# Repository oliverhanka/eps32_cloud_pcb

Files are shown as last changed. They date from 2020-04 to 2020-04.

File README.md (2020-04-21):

# ESP32 low power sensor node

This is a simplistic ESP32 based sensor node with a focus on very low power consumption while beeing idle. This means, external components are keept to a minimum and the selected LDO has a very low power consumption. The board can be supplied with 3.3V directly or by using the on-board LDO (max. 6V input) to generate the required 3.3V. *NOTE: The LDO_EN solder jumper must be closed in order to use the LDO.*

#### Theoretical power consumption
These values have not been verified by measurements and do not take the passive components into account.

Power consumption while beeing in hibernation:
| Active component | Current | Power |
| --- | --- | --- |
| ESP32 (in hibernation)  | 5𝜇A @ 3.3V  | 16.5𝜇W |
| LDO  | 8𝜇A @ 5V  | 40𝜇W |
| **Total**  | **11.3𝜇A @ 5V**  | **56.5𝜇W** |

While beeing active and transmitting via Wifi (BLE off):
| Active component | Current | Power |
| --- | --- | --- |
| ESP32 (240MHz, Wifi tx)  | 240mA @ 3.3V  | 792mW |
| LDO  | 8𝜇A @ 5V  | 40𝜇W |
| **Total**  | **158.4mA @ 5V**  | **792mW** |

## Connectors / headers / solder jumper

| Connector | Purpose |
| --- | --- |
| J1 | I2C, power via GPIO14 |
| J2 | power connector, JST-PH |
| J3 | power connector, USB-C |
| J4 | programming interface, compatible with [ESP-Prog](https://github.com/espressif/esp-iot-solution/blob/master/documents/evaluation_boards/ESP-Prog_guide_en.md) |
| J5 | various GPIOs or ADC and SPI, VCC, GND |
| J6 | GPIO (e.g., for WS2812, power via GPIO2) |

| Solder jumper | Purpose |
| --- | --- |
| LED_EN | Enable blue LED D1 controlled by GPIO12) |
| LDO_EN | Enable LDO (e.g., for power via USB-C) |

## Build

### Manufactured PCB 
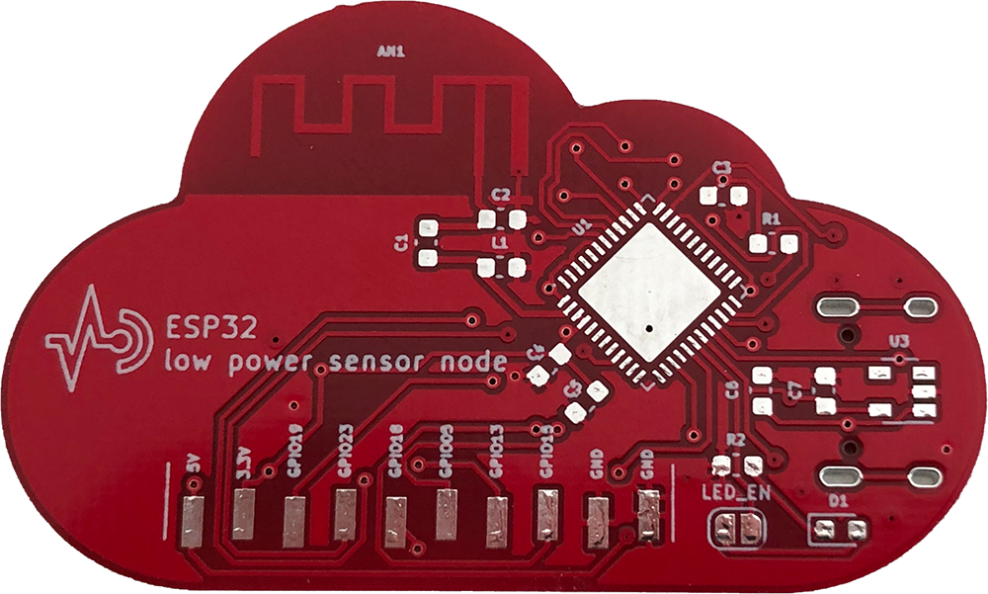
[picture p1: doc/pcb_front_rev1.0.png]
PCB front
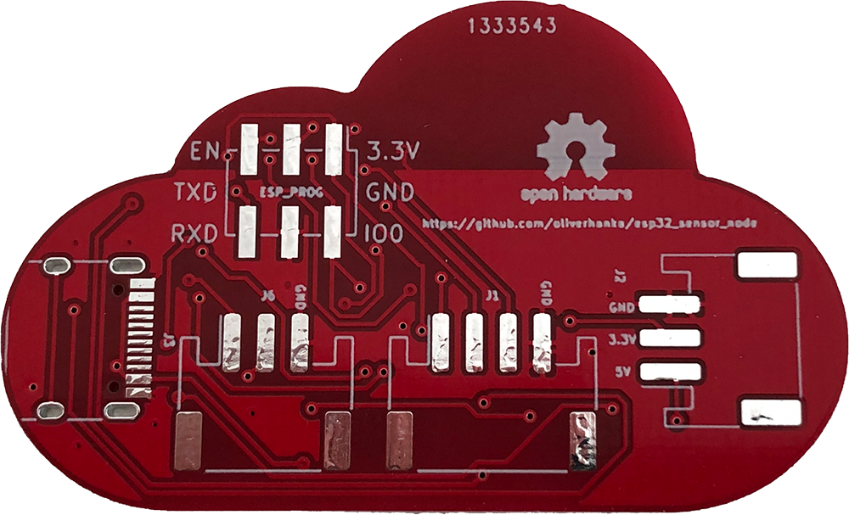
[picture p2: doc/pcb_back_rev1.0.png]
PCB back
 | 
------------ | -------------
frontside rev 1.0 | backside rev 1.0

### Assembled PCB

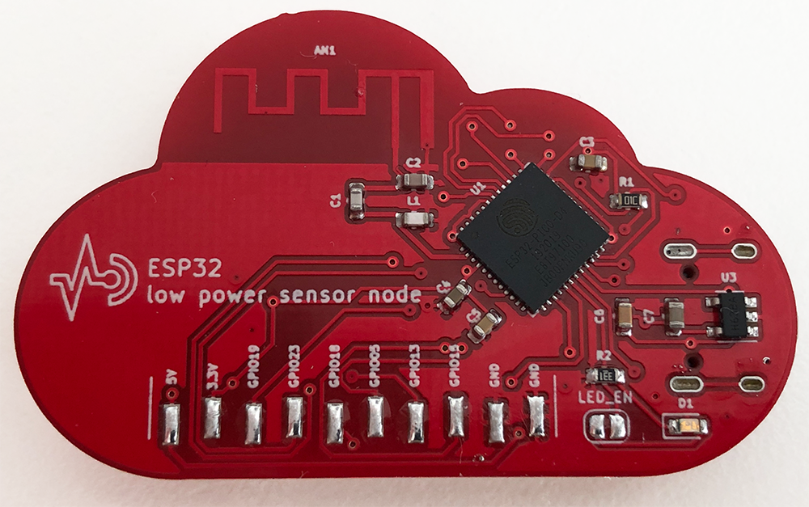
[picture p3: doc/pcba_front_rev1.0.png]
PCBA front
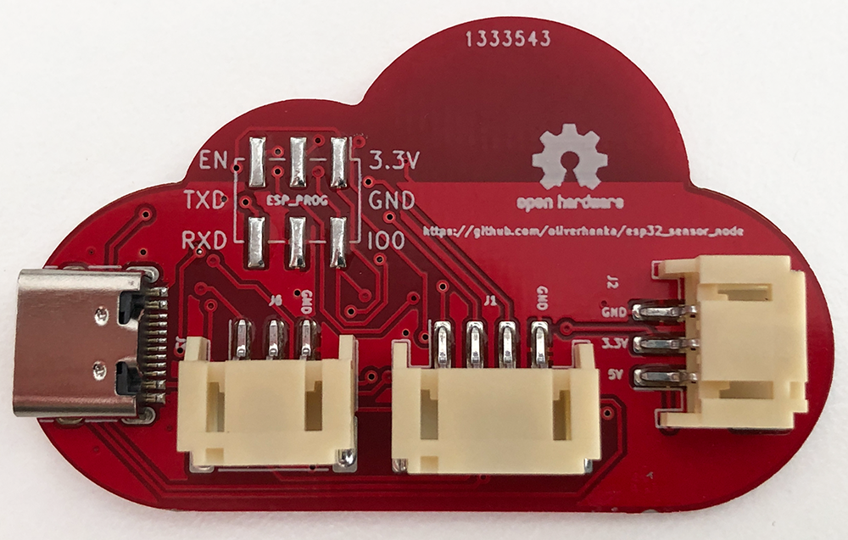
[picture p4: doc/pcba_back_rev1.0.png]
PCBA back
 | 
------------ | -------------
assembled front rev 1.0 | assembled back rev 1.0

### Bill of materials (BOM)

| Designator | Manufacturer Part Number | Qty |
| --- | --- |	--- |
|J6, J2 |	S3B-PH-SM4-TB(LF)(SN) |	2 |
|J1 |	S4B-PH-SM4-TB(LF)(SN) |	1 |
|J3 |	TYPE-C-31-M-12 |	1 |
|R1 |	10kΩ (0603) |	1 |
|R2 |	330Ω (0603) |	1 |
|D1 |	LED (0603) |	1 |
|L1 |	1.6nH (0603) |	1 |
|C7 |	22uF (0603) |	1 |
|C6 |	0.1uf (0603) |	1 |
|C5, C3 |	0.1uF/25V (0603) |	2 |
|C4 |	10uF/6.3V (0603) |	1 |
|C2 |	2.7pF (0603) |	1 |
|C1 |	4.7pF (0603) |	1 |
|U1 |	ESP32-PICO-D4 |	1 |
|U3 |	XC6220B331MR-G |	1 |

---

## Changelog
rev 1.2
- **BREAKING CHANGE**: J6 GPIOs reassigned to GPIO 32 and GPIO 33. GPIO 32 & 33 can be used as ADC1 channels.

rev 1.1
- FIX: U3's EN pin pulled to VCC

rev 1.0
- Initial PCB layout

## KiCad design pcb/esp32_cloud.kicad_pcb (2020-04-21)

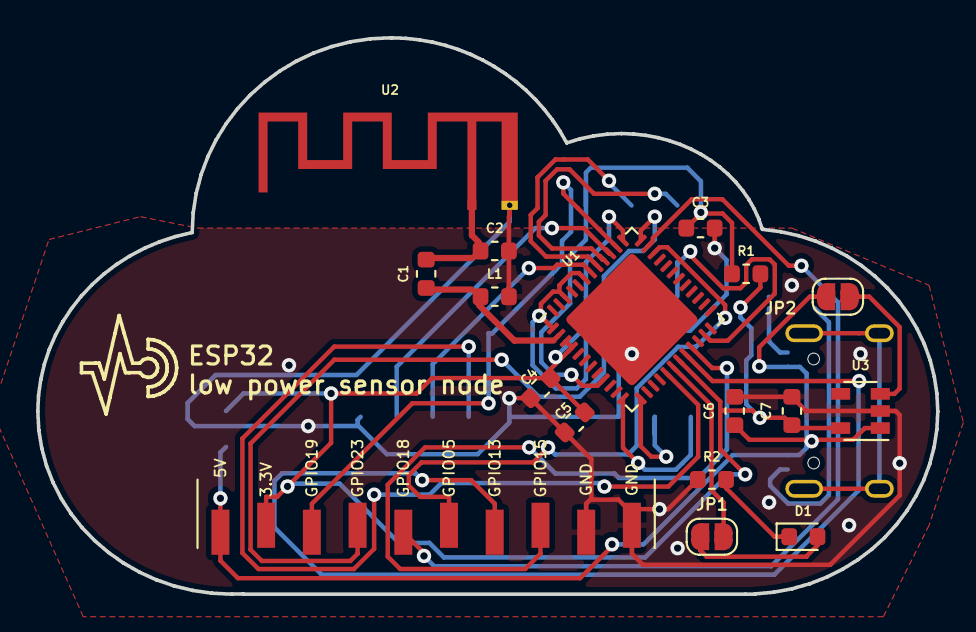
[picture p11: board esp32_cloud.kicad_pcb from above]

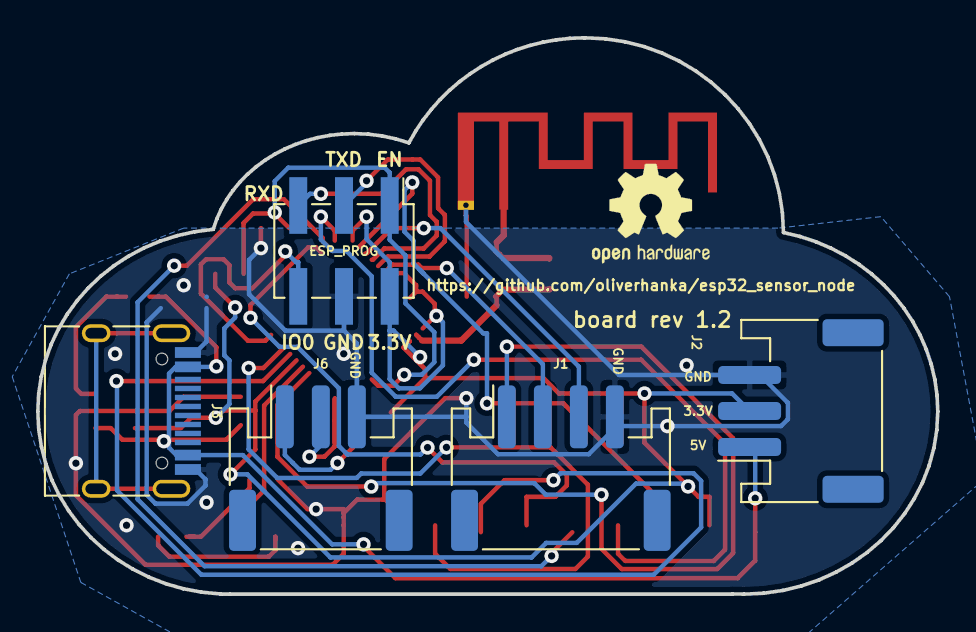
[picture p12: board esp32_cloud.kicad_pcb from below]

Board: 2 copper layers, 50.0 x 30.9 mm, 22 parts (5 on the bottom side), 24 nets.

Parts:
C1: 4.7pF; C_0603_1608Metric
C2: 2.7pF; C_0603_1608Metric
C3, C5: 0.1uF/25V; C_0603_1608Metric
C4: 10uF/6.3V; C_0603_1608Metric
C6: 0.1uF; C_0603_1608Metric
C7: 22uF; C_0603_1608Metric
D1: LED; LED_0603_1608Metric
J1: Conn_01x04_Male; JST_PH_S4B-PH-SM4-TB_1x04-1MP_P2.00mm_Horizontal
J2, J6: Conn_01x03_Male; JST_PH_S3B-PH-SM4-TB_1x03-1MP_P2.00mm_Horizontal
J3: USB_C_Receptacle_USB2.0; USB_C_Receptacle_HRO_TYPE-C-31-M-12
J4: Conn_01x06_Male; PinHeader_2x03_P2.54mm_Vertical_SMD
J5: Conn_01x10_Male; PinHeader_1x10_P2.54mm_Vertical_SMD_Pin1Left
JP1, JP2: Jumper_NO_Small; SolderJumper-2_P1.3mm_Open_RoundedPad1.0x1.5mm
L1: 1.6nH; L_0603_1608Metric
R1: 10k; R_0603_1608Metric
R2: 330; R_0603_1608Metric
U1: ESP32-PICO-D4; QFN-48-1EP_7x7mm_P0.5mm_EP5.3x5.3mm
U2: AN91445; Texas_SWRA117D_2.4GHz_Left
U3: XC6220B331MR; SOT-23-5

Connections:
+3.3VA: C4.1, C5.1, C7.1, J2.2, J4.2, J5.2, R1.1, U1.1, U1.3, U1.4, U1.19, U1.37, U1.43, U1.46, U3.5
+5V: C6.1, J2.1, J3.A4, J3.A9, J3.B4, J3.B9, J5.1, JP2.2, U3.1
/BME280_SCL: J1.3, U1.39
/BME280_SDA: J1.2, U1.42
/BME280_VCC: J1.1, U1.17
/EN: C3.1, J4.1, R1.2, U1.9
/GPIO5_CS0: J5.6, U1.34
/GPIO13_ADC2_CH4: J5.7, U1.20
/GPIO15_ADC2_CH3: J5.8, U1.21
/GPIO18_CLK: J5.5, U1.35
/GPIO19_MISO: J5.3, U1.38
/GPIO23_MOSI: J5.4, U1.36
/GPIO32: J6.1, U1.12
/GPIO33: J6.2, U1.13
/IO0: J4.6, U1.23
/LED_GPIO: JP1.2, U1.18
/RXD: J4.5, U1.40
/TXD: J4.3, U1.41
GND: C2.1, C3.2, C4.2, C5.2, C6.2, C7.2, J1.4, J2.3, J3.A1, J3.A12, J3.B1, J3.B12, J4.4, J5.9, J5.10, J6.3, L1.1, R2.2, U1.49, U2.2, U3.2
unnamed: C1.1, C2.2, U2.1
unnamed: C1.2, L1.2, U1.2
unnamed: D1.1, R2.1
unnamed: D1.2, JP1.1
unnamed: JP2.1, U3.3

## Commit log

2020-04-09 rev 1.1
    [esp32_cloud.kicad_pcb, esp32_cloud.sch]
2020-04-21 J6 changed from ADC2 to ADC1 GPIOs
    [esp32_cloud.kicad_pcb, esp32_cloud.sch]
